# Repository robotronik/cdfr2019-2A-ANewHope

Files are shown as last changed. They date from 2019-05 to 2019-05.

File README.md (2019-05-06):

# Robot 2A Martine - A New Hope

## Contexte et objectifs:
La carte de la base roulante et celle de l'ascenseur initialement prévues ne pourront pas etre prêtes dans les temps. Après discusion avec l'équipe du robot 1A, il n'y a que peu de choses sur lesquelles preter main forte. Il serait donc possible de continuer à travailler sur le robot 2A pour pouvoir présenter une version minimale de celui-ci à la coupe.

L'objectif serait de passer l'homologation et de pouvoir pousser quelques palets au cours de la coupe. Pour espérer être dans les temps, il est vital de faire au plus simple afin de disposer d'une base méca/elec prete, avec le code haut niveau à faire sur la route.

La version B du robot abandonne l'ascenseur pour ne garder qu'un étage base roulante + un étage contrôle. D'un point de vue mécanique: la base roulante est quasiment prête et l'étage de controle peut être assemblé rapidement.

Volontaires:
* Victor (Mécanique, Elec)
* Félix (Elec)
* Raphael (Elec: Carte alimentation & Code)
* Arnaud (Elec: carte ultrason)

Conseil:
* Iris (Mécanique)

A confirmer:
* Vincent (Elec et prog?)

## Nouvelle structure:
Après discution avec Felix, Iris et Luc: idéalement, il aurait fallu récupérer la carte de la base roulante de l'année dernière, mais le STM32 dessus étant mort, et des levels shifters devant etre implémentés, faire rapidement une nouvelle carte est plus simple. La nouvelle structure serait donc la suivante (en gras: les cartes électroniques):

* Etage de contrôle:
  * **Carte de controle (CC)**:
    * [STM32 Nucleo-64 F401RE](https://www.st.com/en/evaluation-tools/nucleo-f401re.html)
  * **Carte d'alimentation**
  * Batterie
* Etage base roulante (Méca finie)
  * Moteurs (En place)
  * [Ecodeurs UsDigital S4T](https://www.usdigital.com/products/encoders/incremental/rotary/shaft/S4T?specification=mechanical#description) (En place)
  * Capteurs ultrasons (ref à définir)
  * **Carte adaptateur nappe moteur-pin** (car réutilisable facilement si à part)
  * **Carte de controle base roulante (CBR)**:
    * [Nucleo-32 F303K8](https://www.st.com/en/evaluation-tools/nucleo-f303k8.html) de format Arduino Nano, programmable avec l'IDE Arduino
    * Level shifters pour communiquer avec les encodeurs ([par exemple ceux-ci](https://www.sparkfun.com/products/12009))
    * Driver moteurs: à commander et si possible à integrer directement sur la carte
  * **Carte capteur ultrasons (CU)**

## Avancement:

Tâches de la partie méca (Victor):
* Impression des dernieres équerres
* Assemblage de l'étage de controle
* Découpe au fablab des parois/bases plexiglass
* Design et impression (ou adaptation) de supports pour les cartes électroniques

Tâches de la partie électronique:
* Carte alimentation à finir (Raph')
* Carte base roulante à faire (Victor & Félix)
* Carte nappe moteur-pin à vérifier et imprimer
* Carte ultrason à faire (Arnaud)

Tâches de de partie Code:
* Finir l'asservissement PID (nécessite la base roulante prete) (Raph')

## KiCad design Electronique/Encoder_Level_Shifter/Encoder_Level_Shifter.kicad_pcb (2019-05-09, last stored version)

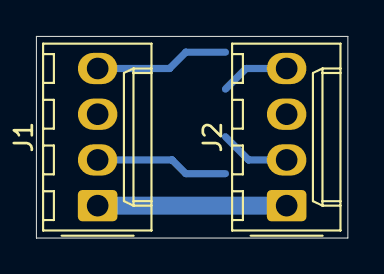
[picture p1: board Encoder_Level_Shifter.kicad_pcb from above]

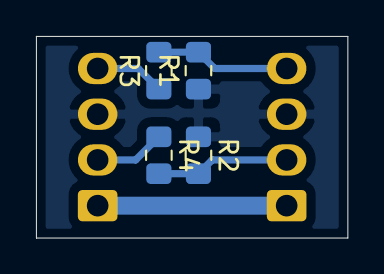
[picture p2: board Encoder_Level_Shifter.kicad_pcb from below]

Board: 2 copper layers, 17.3 x 11.2 mm, 6 parts (4 on the bottom side), 6 nets.

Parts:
J1, J2: Conn_01x04; Molex_KK-254_AE-6410-04A_1x04_P2.54mm_Vertical
R1, R2: 10k; R_0805_2012Metric_Pad1.15x1.40mm_HandSolder
R3, R4: 5.4k; R_0805_2012Metric_Pad1.15x1.40mm_HandSolder

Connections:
+5V: J1.1, J2.1
/A_In: J2.2, R4.1
/A_Out: J1.2, R2.2, R4.2
/B_In: J2.4, R3.1
/B_Out: J1.4, R1.2, R3.2
GND: J1.3, J2.3, R1.1, R2.1

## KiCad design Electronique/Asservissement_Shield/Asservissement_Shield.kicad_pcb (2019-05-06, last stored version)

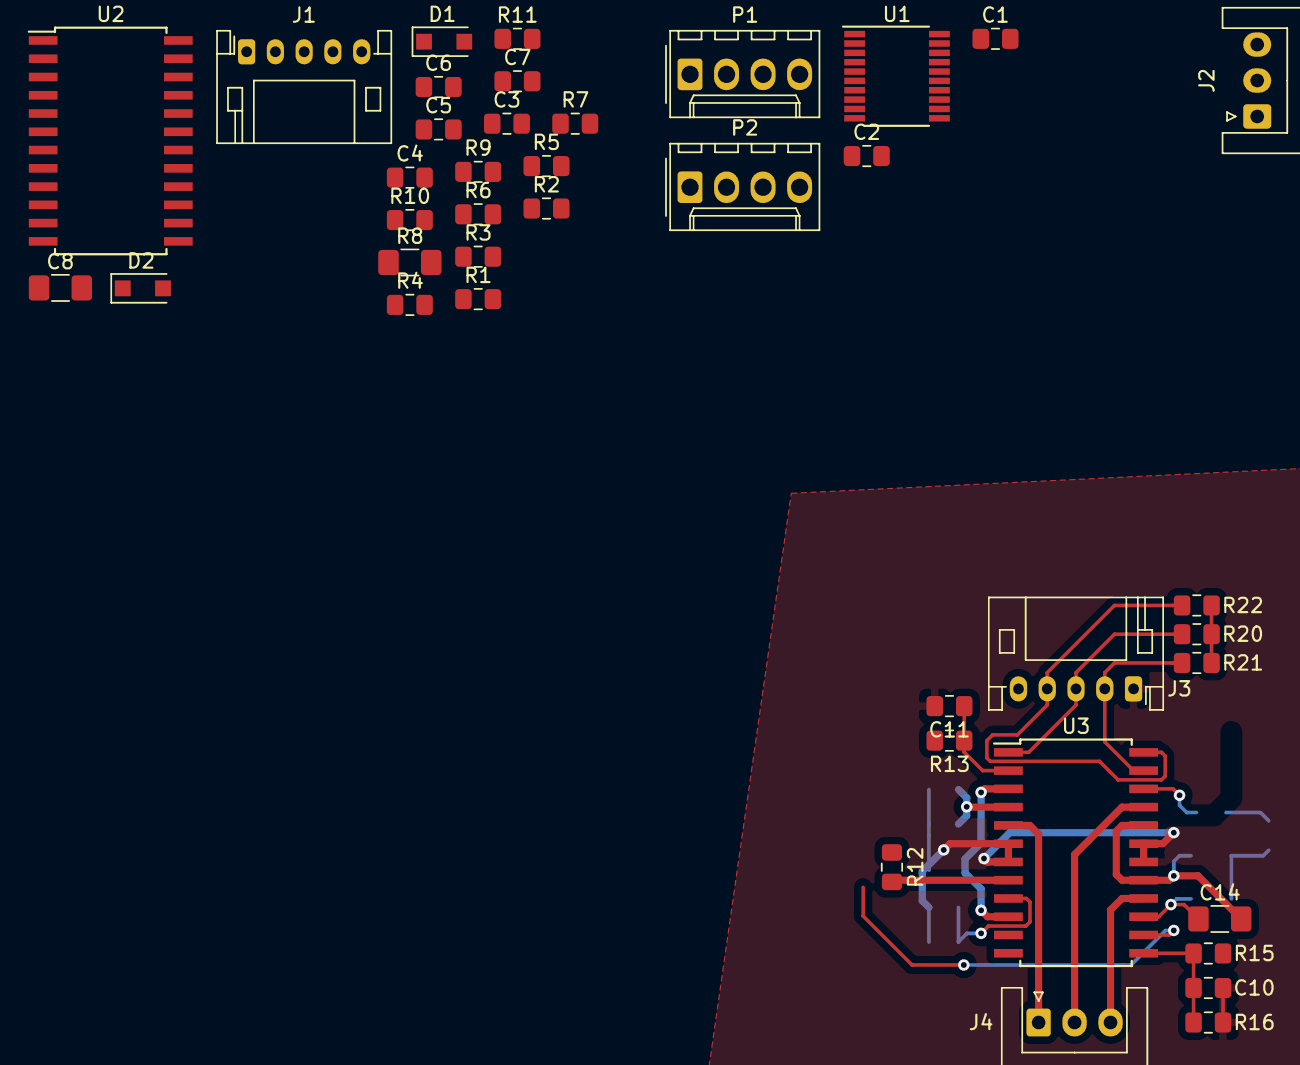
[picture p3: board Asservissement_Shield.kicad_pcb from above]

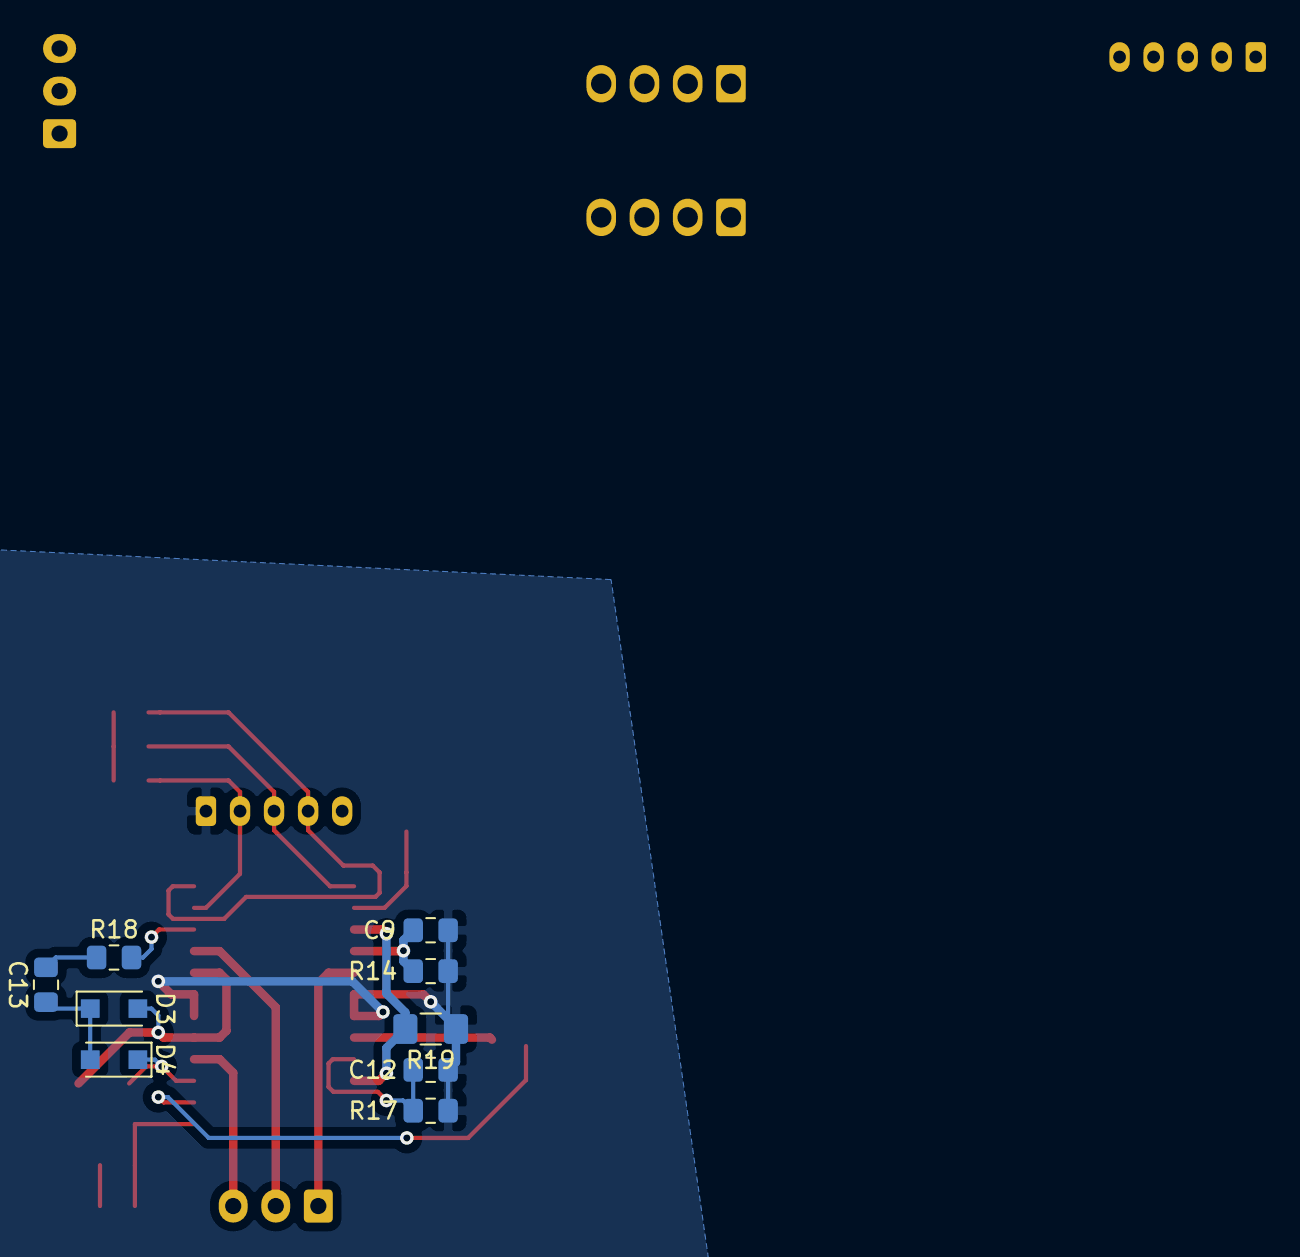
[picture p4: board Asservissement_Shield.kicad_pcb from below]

Board: 2 copper layers, 49 parts (9 on the bottom side), 40 nets.

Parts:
C1, C2: 100n; C_0805_2012Metric_Pad1.15x1.40mm_HandSolder
C3, C6, C9, C12: 1n; C_0805_2012Metric_Pad1.15x1.40mm_HandSolder
C4, C7, C10, C13: 10n; C_0805_2012Metric_Pad1.15x1.40mm_HandSolder
C5, C11: 5.6n; C_0805_2012Metric_Pad1.15x1.40mm_HandSolder
C8, C14: 220n; C_1206_3216Metric_Pad1.42x1.75mm_HandSolder
D1, D2, D3, D4: 1N4148; D_SOD-123F
J1, J3: Hall_Sensor; JST_PH_S5B-PH-K_1x05_P2.00mm_Horizontal
J2, J4: Windings; JST_XH_S3B-XH-A_1x03_P2.50mm_Horizontal
P1, P2: encoder_2; Molex_KK-254_AE-6410-04A_1x04_P2.54mm_Vertical
R1, R12: 1k; R_0805_2012Metric_Pad1.15x1.40mm_HandSolder
R2, R13: 100k; R_0805_2012Metric_Pad1.15x1.40mm_HandSolder
R3, R14: 35k; R_0805_2012Metric_Pad1.15x1.40mm_HandSolder
R4, R15: 1k2; R_0805_2012Metric_Pad1.15x1.40mm_HandSolder
R5, R16: 220; R_0805_2012Metric_Pad1.15x1.40mm_HandSolder
R6, R17: 47k; R_0805_2012Metric_Pad1.15x1.40mm_HandSolder
R7, R18: 100; R_0805_2012Metric_Pad1.15x1.40mm_HandSolder
R8, R19: 0.3; R_1206_3216Metric_Pad1.42x1.75mm_HandSolder
R9, R10, R11, R20, R21, R22: 0; R_0805_2012Metric_Pad1.15x1.40mm_HandSolder
U1: TXS0108EPW; TSSOP-20_4.4x6.5mm_P0.65mm
U2, U3: L6235PD; SOIC-24W_7.5x15.4mm_P1.27mm

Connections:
+3V3: C1.1, R1.1, R4.1, R12.1, R15.1, U1.2, U1.10
+5V: C2.1, P1.1, P2.1, R9.1, R10.1, R11.1, R20.1, R21.1, R22.1, U1.19
/Diagnostic_1: C11.1, R13.1, U3.2, U3.12
/Diagnostic_2: C5.1, R2.1, U2.2, U2.12
/Encoders/Ch_A1(+5V): P1.2, U1.15
/Encoders/Ch_A2(+5V): P2.2, U1.13
/Encoders/Ch_B1(+5V): P1.4, U1.14
/Encoders/Ch_B2(+5V): P2.4, U1.12
/MotorA/Hall_Sensor1: J1.3, R9.2, U2.1
/MotorA/Hall_Sensor2: J1.2, R10.2, U2.23
/MotorA/Hall_Sensor3: J1.4, R11.2, U2.24
/MotorA/Motor_Winding1: J2.1, U2.5
/MotorA/Motor_Winding2: J2.2, U2.21
/MotorA/Motor_Winding3: J2.3, U2.16
/MotorB/Hall_Sensor1: J3.3, R20.2, U3.1
/MotorB/Hall_Sensor2: J3.2, R21.2, U3.23
/MotorB/Hall_Sensor3: J3.4, R22.2, U3.24
/MotorB/Motor_Winding1: J4.1, U3.5
/MotorB/Motor_Winding2: J4.2, U3.21
/MotorB/Motor_Winding3: J4.3, U3.16
/Tachometer_1: R12.2, U3.8
/Tachometer_2: R1.2, U2.8
GND: C1.2, C2.2, C3.2, C4.2, C5.2, C6.2, C9.2, C10.2, C11.2, C12.2, J1.1, J3.1, P1.3, P2.3, R3.2, R5.2, R6.2, R8.1, R14.2, R16.2, R17.2, R19.1, U1.11, U2.6, U2.7, U2.18, U2.19, U3.6, U3.7, U3.18, U3.19
unnamed: C3.1, R3.1, U2.4
unnamed: C4.1, R4.2, R5.1, U2.13
unnamed: C6.1, R6.1, U2.9
unnamed: C7.1, D1.1, D2.2
unnamed: C7.2, R7.1
unnamed: C8.1, D2.1, U2.15
unnamed: C9.1, R14.1, U3.4
unnamed: C10.1, R15.2, R16.1, U3.13
unnamed: C12.1, R17.1, U3.9
unnamed: C13.1, D3.1, D4.2
unnamed: C13.2, R18.1
unnamed: C14.1, D4.1, U3.15
unnamed: R7.2, U2.22
unnamed: R8.2, U2.3, U2.10
unnamed: R18.2, U3.22
unnamed: R19.2, U3.3, U3.10
VCC: C8.2, C14.2, D1.2, D3.2, U2.17, U2.20, U3.17, U3.20

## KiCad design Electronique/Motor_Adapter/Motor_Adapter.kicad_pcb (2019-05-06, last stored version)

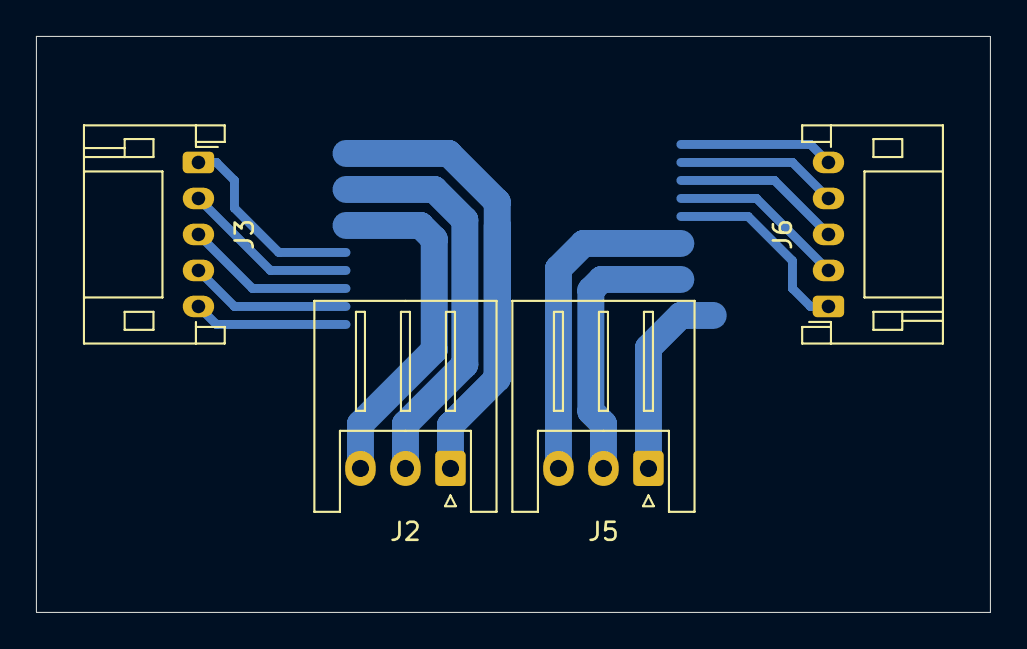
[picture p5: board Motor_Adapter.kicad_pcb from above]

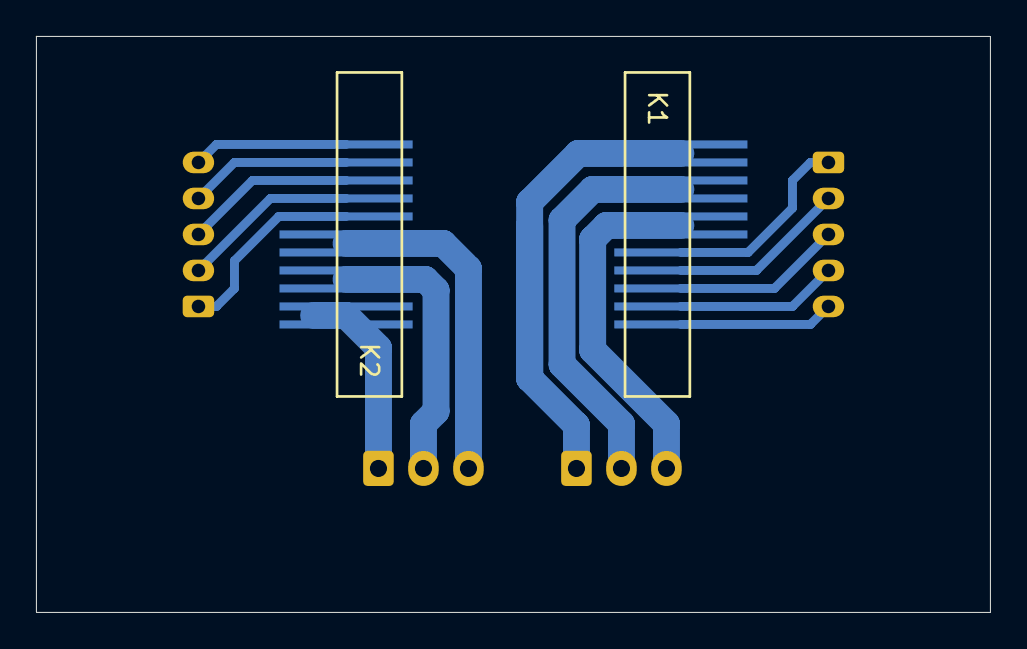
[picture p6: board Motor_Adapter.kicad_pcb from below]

Board: 2 copper layers, 53.0 x 32.0 mm, 6 parts (2 on the bottom side), 16 nets.

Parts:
J2, J5: Windings; JST_XH_S3B-XH-A_1x03_P2.50mm_Horizontal
J3, J6: Hall_Sensor; JST_PH_S5B-PH-K_1x05_P2.00mm_Horizontal
K1, K2: Maxon-200142; Molex-52610-1133

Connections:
unnamed: J2.1, K1.1, K1.2
unnamed: J2.2, K1.3, K1.4
unnamed: J2.3, K1.5, K1.6
unnamed: J3.1, K1.7
unnamed: J3.2, K1.8
unnamed: J3.3, K1.9
unnamed: J3.4, K1.10
unnamed: J3.5, K1.11
unnamed: J5.1, K2.1, K2.2
unnamed: J5.2, K2.3, K2.4
unnamed: J5.3, K2.5, K2.6
unnamed: J6.1, K2.7
unnamed: J6.2, K2.8
unnamed: J6.3, K2.9
unnamed: J6.4, K2.10
unnamed: J6.5, K2.11

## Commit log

2019-03-08 Code for encoders.
2019-03-08 reset encoders after setup
2019-03-15 adc ok ?
2019-04-10 code for print and encoders tested
2019-04-16 push code for motors
2019-04-29 correct configuration and added make tsmr.debug with triggers gdb
    [gdb-pipe.cfg]
2019-04-29 interruptions on timer 15
2019-04-30 motor control with PWM, pins are correct for motors.h
2019-05-01 Weird bug in libopencm3 ? or in stm32 ? Works with this code.
2019-05-01 Update Odometry code (add print, change to delta-theta asser)
2019-05-01 Limit motor currents
2019-05-01 "Final" main function, correct PID.
2019-05-03 Add "calibration.{c,h}". Move asservissement files to asservissement dir.
2019-05-06 Ajout des infos pour l'organisation
2019-05-06 Add electronics (not finished)
    [Asservissement_Shield.kicad_pcb, Asservissement_Shield.sch, Motor_Adapter.kicad_pcb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]
2019-05-06 fix 5v / 3v3
    [motor_driver.sch]
2019-05-09 Add small board for encoder level shifting
    [Encoder_Level_Shifter.kicad_pcb, Encoder_Level_Shifter.sch]
2019-05-09 Ajout Test_ToF
    Jeu de test pour 1 ToF de la carte Ultraphotonic Sense
    [gdb-pipe.cfg, st_nucleo_f3.cfg, st_nucleo_f4.cfg]
2019-05-09 Test_ToToF en callback
    Jeu de test d'1 servo en callback avec un seuil de détection
2019-05-10 Moved code to subdir
    [gdb-pipe.cfg]
2019-05-10 asservissement board works fine
2019-05-13 Clean up
    [Asservissement_Shield.kicad_pcb, Asservissement_Shield.sch, Encoder_Level_Shifter.kicad_pcb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]
